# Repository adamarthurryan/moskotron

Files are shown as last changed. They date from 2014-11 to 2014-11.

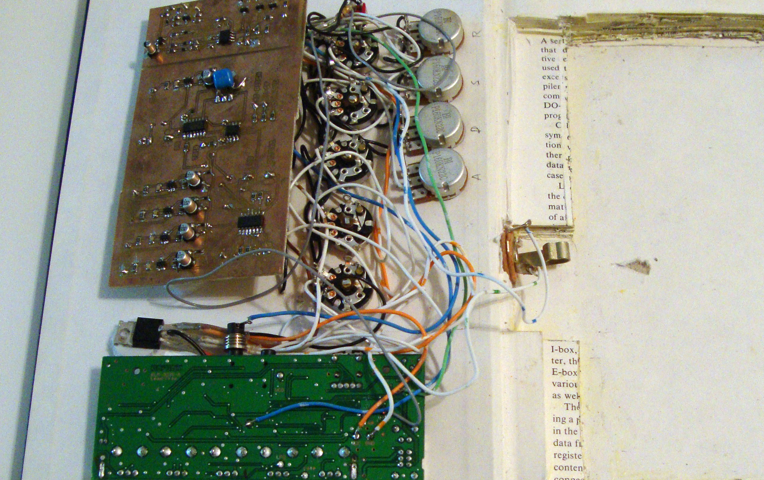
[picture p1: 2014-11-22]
documentation/book open - detail.jpg

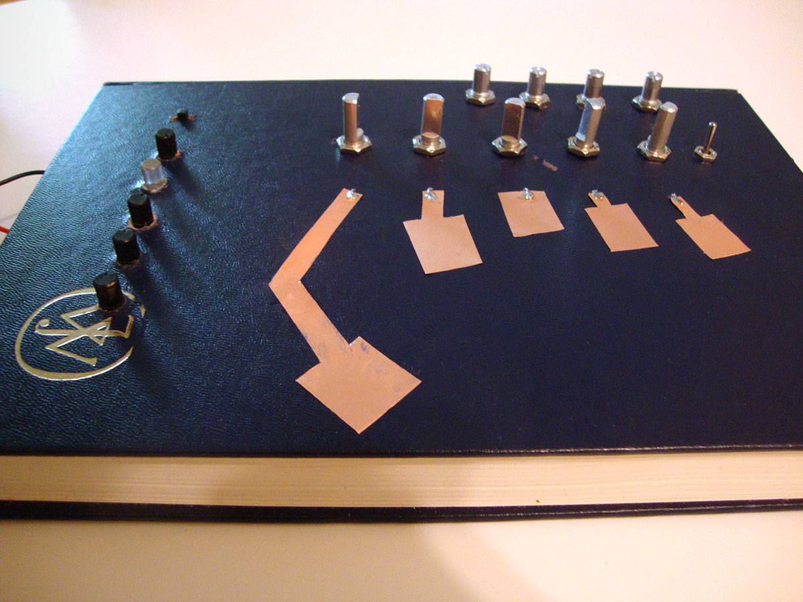
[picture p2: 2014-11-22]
documentation/book closed - small.jpg

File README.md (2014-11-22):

moskotron
=========

A unique analog audio synthesizer. Built with and for Alex Moskos - aka Drainolith. 

Audio is generated by a Korg Monotron, which is extended by wiring in two new boards: 
an ADSR enveloped waveshaper and a 5-key tunable touch keyboard.
The keyboard can be tuned to any scale - conventional, microtonal or weird.

The entire synthesizer was encased in a book - for effect.

See http://madanworb.com/blog/2012/08/15/moskotron/ for video of Alex trying it out for the first time.

Schematics and burnable pcb layouts are available in the documentation folder.

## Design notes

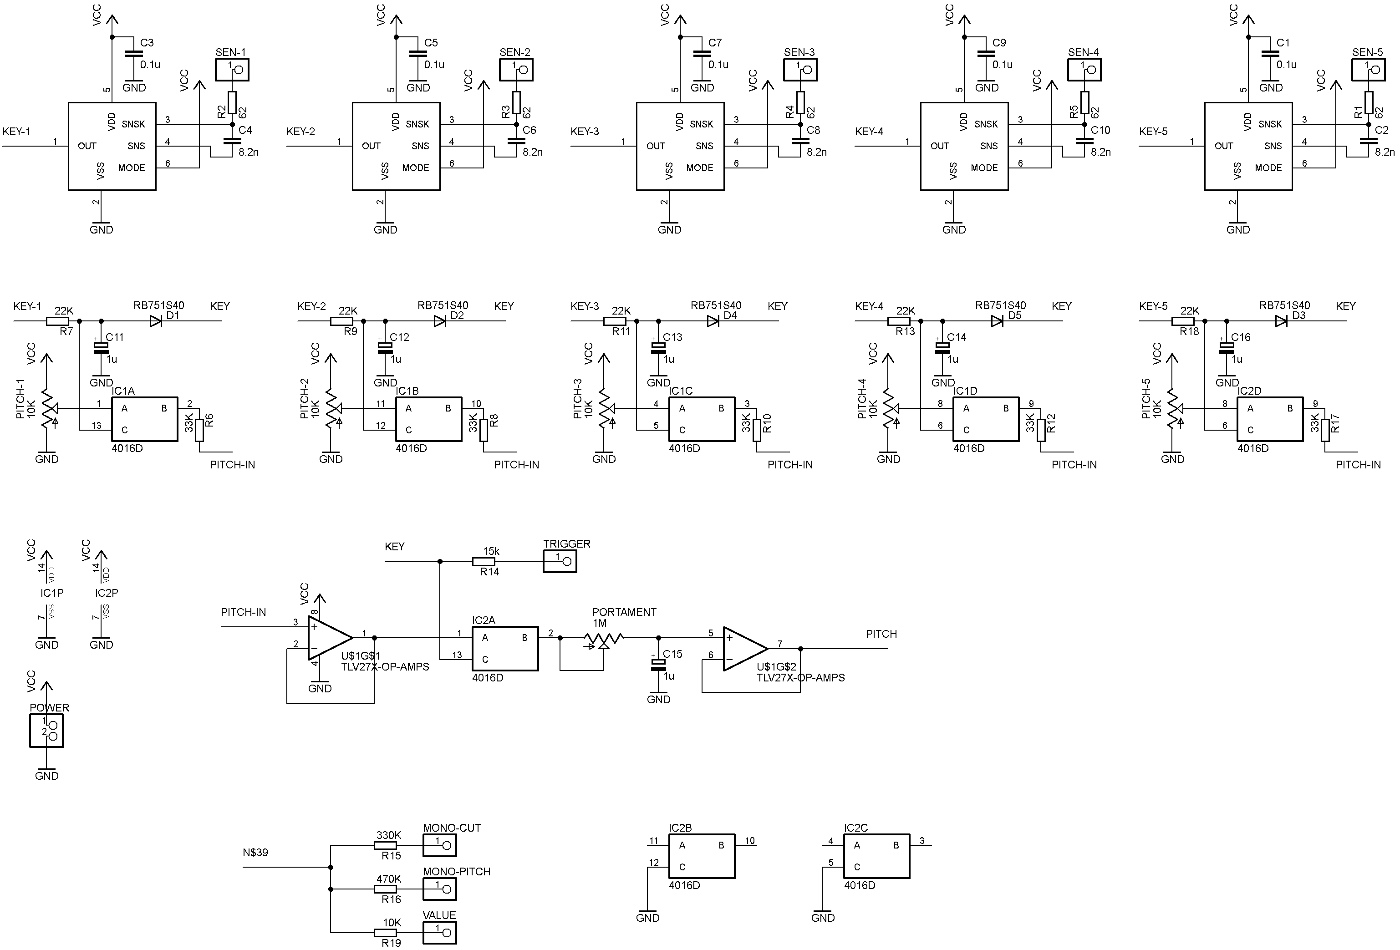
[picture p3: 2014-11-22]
documentation/pitch input schematic.png

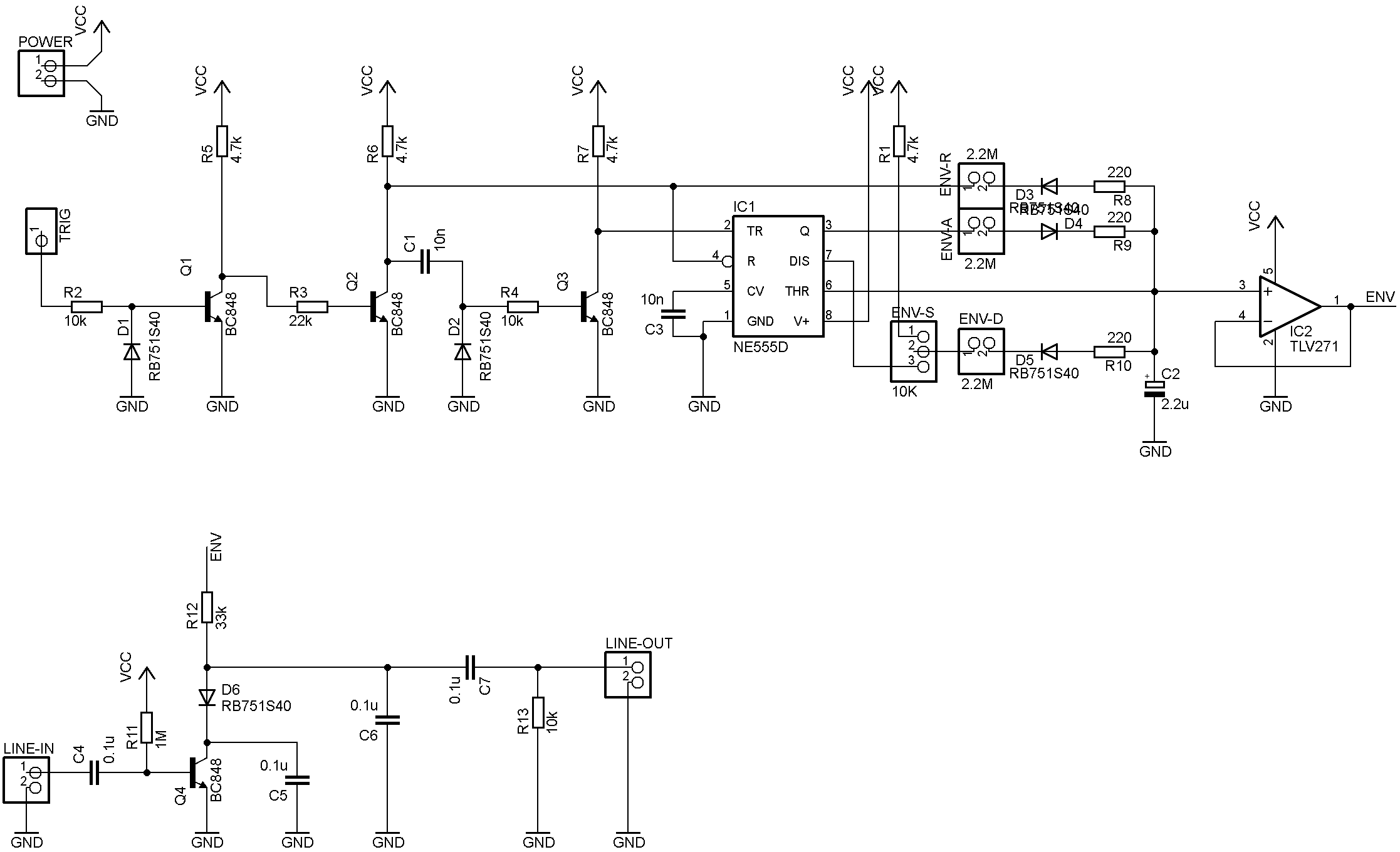
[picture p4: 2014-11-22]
documentation/adsr vca schematic.png

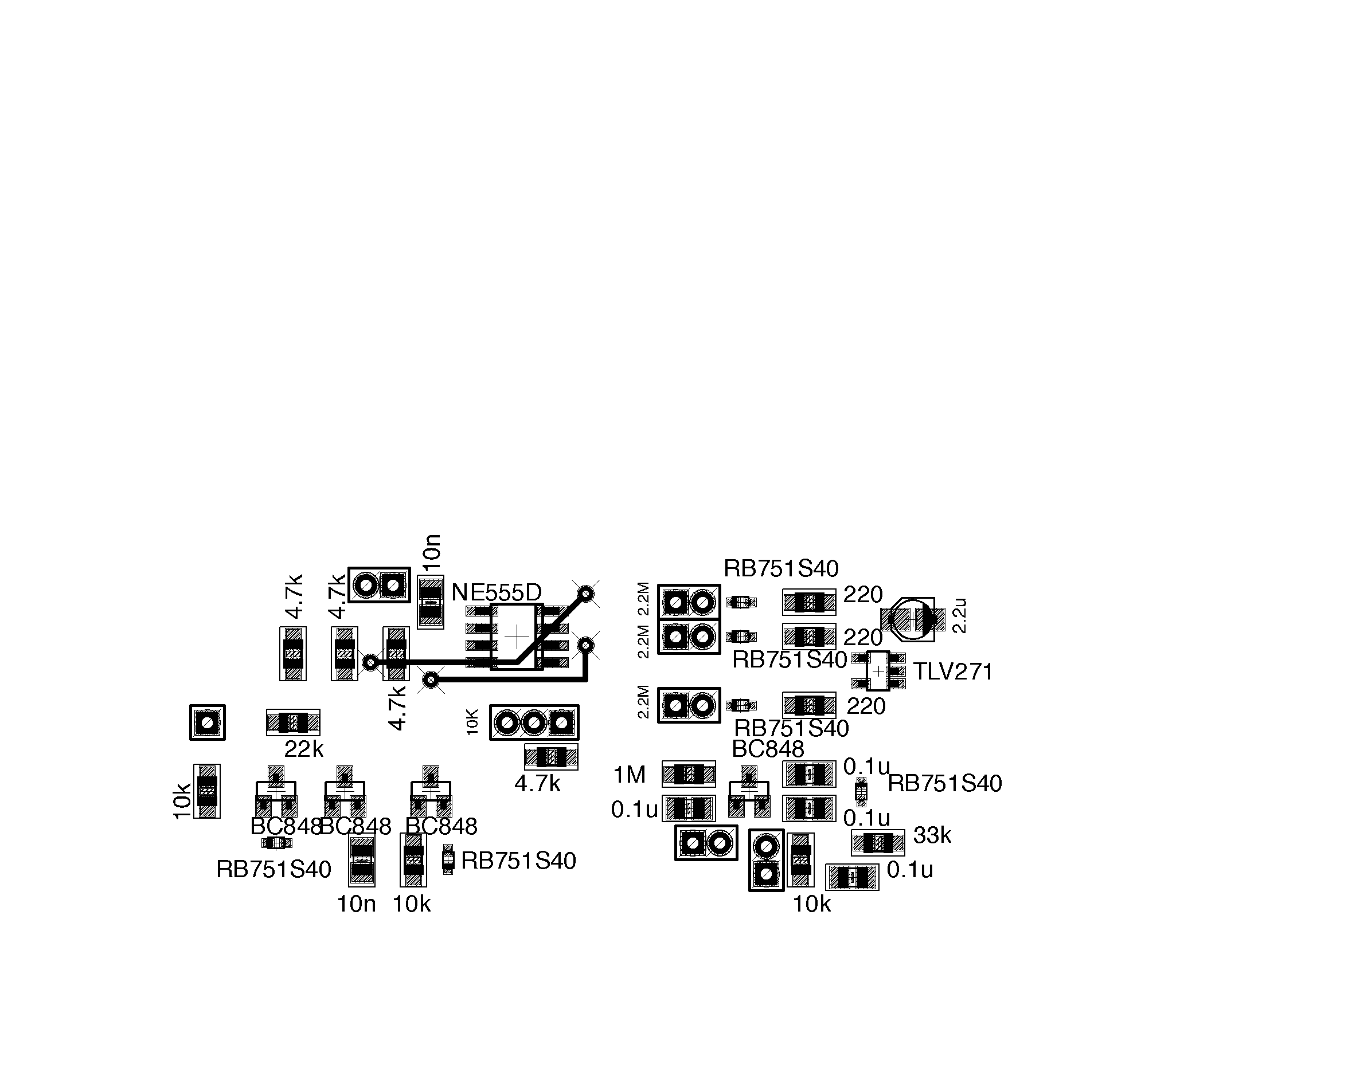
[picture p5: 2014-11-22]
adsr and vca/placement.png

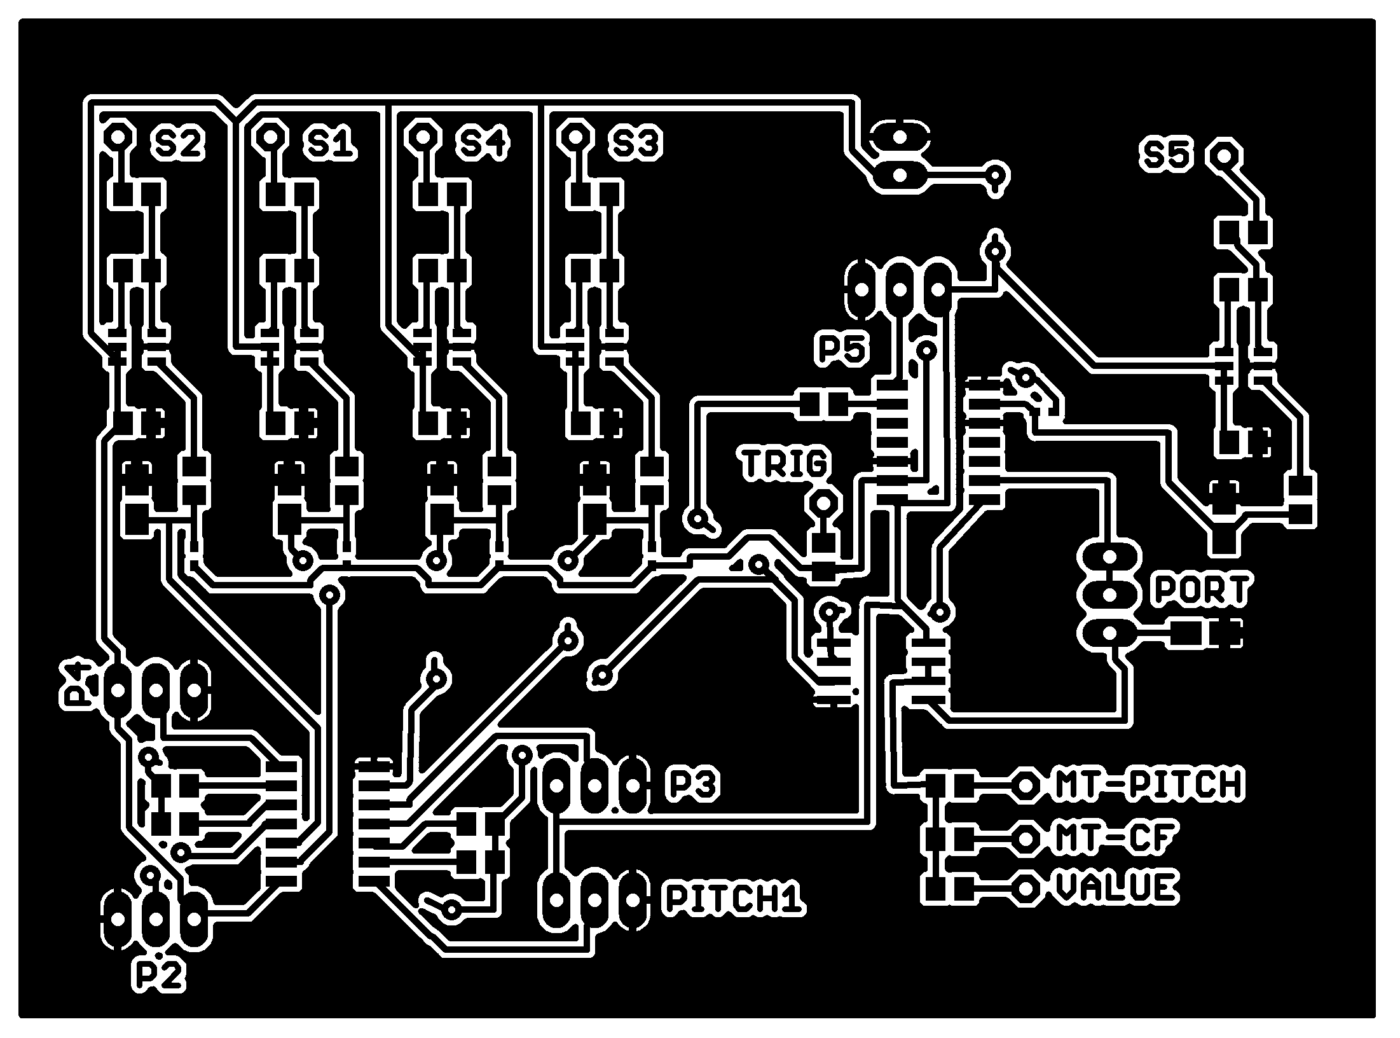
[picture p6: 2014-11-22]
pitch input/top.png

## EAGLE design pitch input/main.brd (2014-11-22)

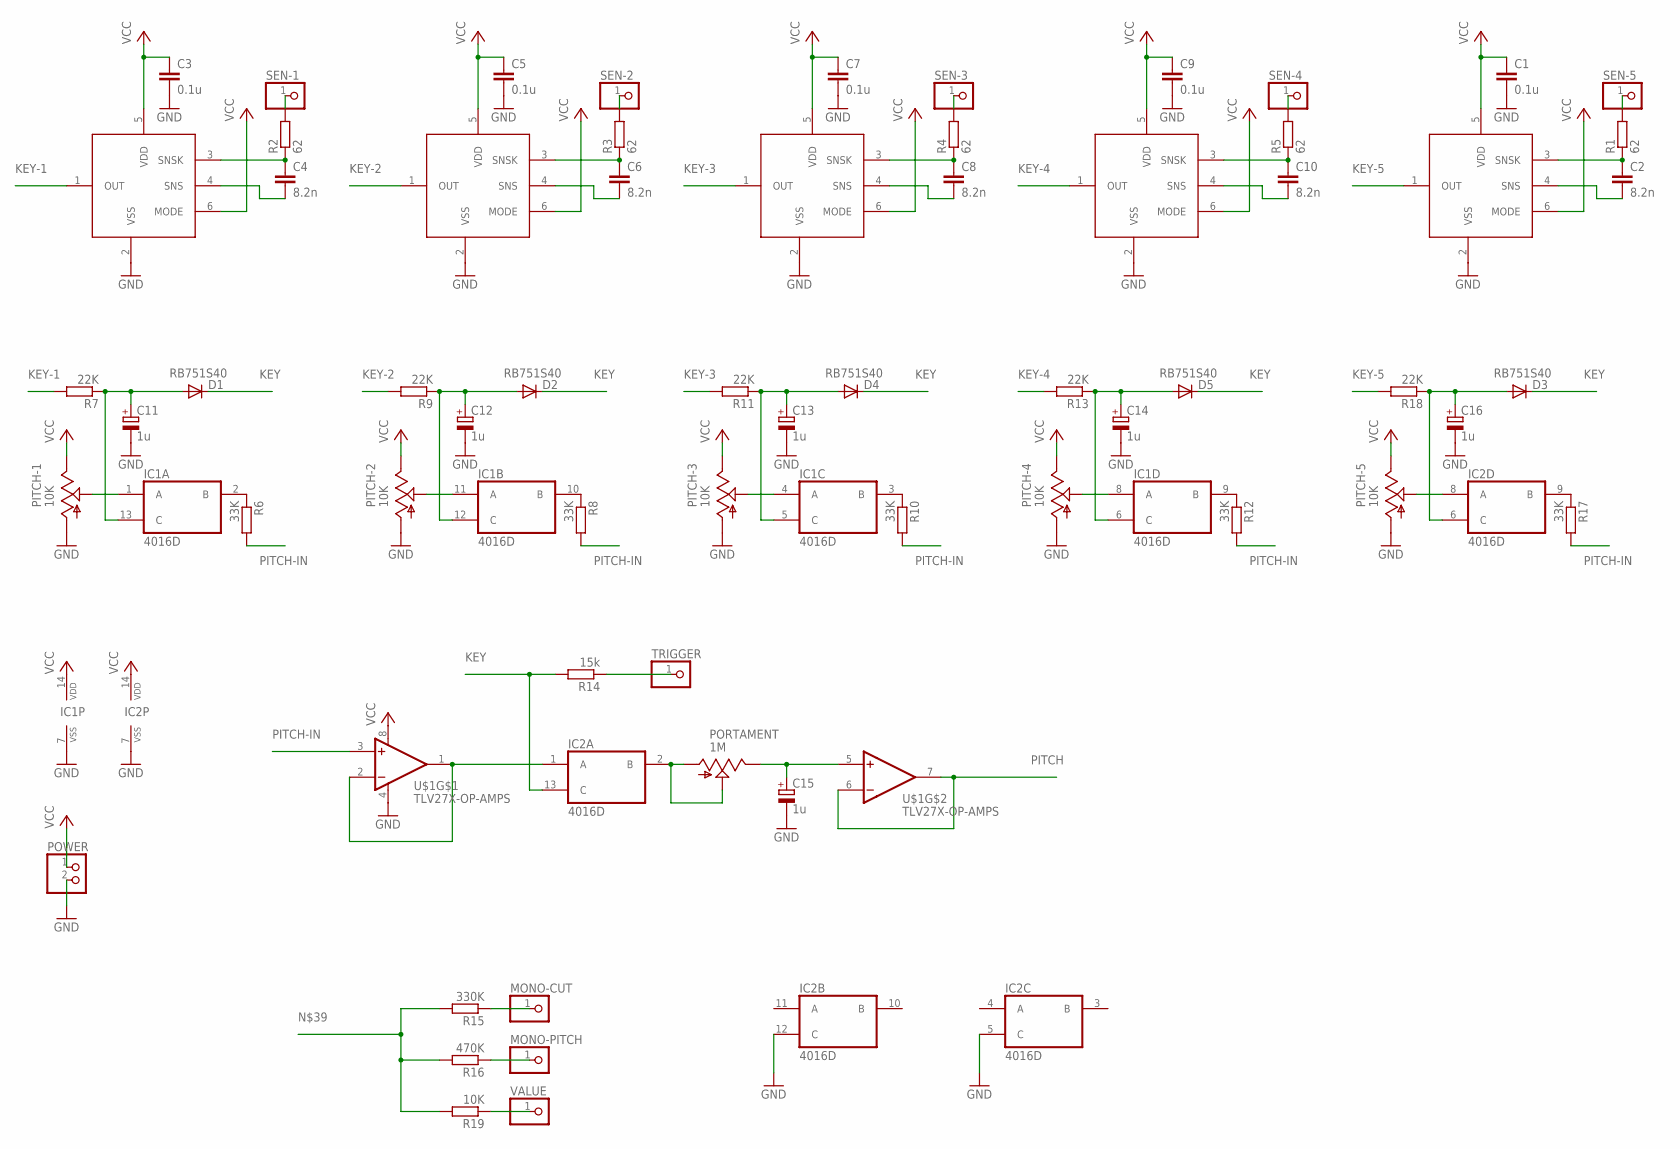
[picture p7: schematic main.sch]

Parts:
C1, C3, C5, C7, C9: 0.1u; C0805
C2, C4, C6, C8, C10: 8.2n; C0805
C11, C12, C13, C14, C15, C16: 1u; PANASONIC_A
D1, D2, D3, D4, D5: RB751S40; SOD523
IC1, IC2: 4016D; SO14
MONO-CUT: PINHD-1X1; 1X01
MONO-PITCH: PINHD-1X1; 1X01
PITCH-1, PITCH-2, PITCH-3, PITCH-4, PITCH-5: 10K; PIN-1X03
PORTAMENT: 1M; PIN-1X03
POWER: PINHD-1X2; 1X02
R1, R2, R3, R4, R5: 62; R0805
R6, R8, R10, R12, R17: 33K; R0805
R7, R9, R11, R13, R18: 22K; R0805
R14: 15k; R0805
R15: 330K; R0805
R16: 470K; R0805
R19: 10K; R0805
SEN-1, SEN-2, SEN-3, SEN-4, SEN-5: PINHD-1X1; 1X01
TRIGGER: PINHD-1X1; 1X01
U$1: TLV27X-OP-AMPS; SOIC8
U$2, U$3, U$4, U$5, U$6: AT42QT1010; SOT23-6L
VALUE: PINHD-1X1; 1X01

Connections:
GND: C1.2, C3.2, C5.2, C7.2, C9.2, C11.-, C12.-, C13.-, C14.-, C15.-, C16.-, IC1.7 (VSS), IC2.5 (C), IC2.7 (VSS), IC2.12 (C), PITCH-1.1 (A), PITCH-2.1 (A), PITCH-3.1 (A), PITCH-4.1 (A), PITCH-5.1 (A), POWER.2, U$1.4 (V-), U$2.2 (VSS), U$3.2 (VSS), U$4.2 (VSS), U$5.2 (VSS), U$6.2 (VSS)
KEY: D1.C, D2.C, D3.C, D4.C, D5.C, IC2.13 (C), R14.2
KEY-1: R7.2, U$2.1 (OUT)
KEY-2: R9.2, U$3.1 (OUT)
KEY-3: R11.2, U$4.1 (OUT)
KEY-4: R13.2, U$5.1 (OUT)
KEY-5: R18.2, U$6.1 (OUT)
unnamed: C4.2, U$2.4 (SNS)
unnamed: C4.1, R2.1, U$2.3 (SNSK)
unnamed: R2.2, SEN-1.1
unnamed: C6.2, U$3.4 (SNS)
unnamed: C6.1, R3.1, U$3.3 (SNSK)
unnamed: R3.2, SEN-2.1
unnamed: C8.2, U$4.4 (SNS)
unnamed: C8.1, R4.1, U$4.3 (SNSK)
unnamed: R4.2, SEN-3.1
unnamed: C10.2, U$5.4 (SNS)
unnamed: C10.1, R5.1, U$5.3 (SNSK)
unnamed: R5.2, SEN-4.1
unnamed: IC1.1 (A), PITCH-1.2 (S)
unnamed: IC1.2 (B), R6.1
unnamed: C11.+, D1.A, IC1.13 (C), R7.1
unnamed: IC1.11 (A), PITCH-2.2 (S)
unnamed: IC1.10 (B), R8.1
unnamed: C12.+, D2.A, IC1.12 (C), R9.1
unnamed: IC1.4 (A), PITCH-3.2 (S)
unnamed: IC1.3 (B), R10.1
unnamed: C13.+, D4.A, IC1.5 (C), R11.1
unnamed: IC1.8 (A), PITCH-4.2 (S)
unnamed: IC1.9 (B), R12.1
unnamed: C14.+, D5.A, IC1.6 (C), R13.1
unnamed: IC2.1 (A), U$1.1 (OUT), U$1.2 (-IN)
unnamed: IC2.2 (B), PORTAMENT.1 (A), PORTAMENT.2 (S)
unnamed: MONO-PITCH.1, R16.1
unnamed: C15.+, PORTAMENT.3 (E), U$1.5 (+IN)
unnamed: MONO-CUT.1, R15.1
unnamed: C2.2, U$6.4 (SNS)
unnamed: C2.1, R1.1, U$6.3 (SNSK)
unnamed: R1.2, SEN-5.1
unnamed: IC2.8 (A), PITCH-5.2 (S)
unnamed: C16.+, D3.A, IC2.6 (C), R18.1
unnamed: IC2.9 (B), R17.1
unnamed: R15.2, R16.2, R19.2
unnamed: R19.1, VALUE.1
PITCH: U$1.6 (-IN), U$1.7 (OUT)
PITCH-IN: R6.2, R8.2, R10.2, R12.2, R17.2, U$1.3 (+IN)
TRIG: R14.1, TRIGGER.1
VCC: C1.1, C3.1, C5.1, C7.1, C9.1, IC1.14 (VDD), IC2.14 (VDD), PITCH-1.3 (E), PITCH-2.3 (E), PITCH-3.3 (E), PITCH-4.3 (E), PITCH-5.3 (E), POWER.1, U$1.8 (V+), U$2.5 (VDD), U$2.6 (MODE), U$3.5 (VDD), U$3.6 (MODE), U$4.5 (VDD), U$4.6 (MODE), U$5.5 (VDD), U$5.6 (MODE), U$6.5 (VDD), U$6.6 (MODE)

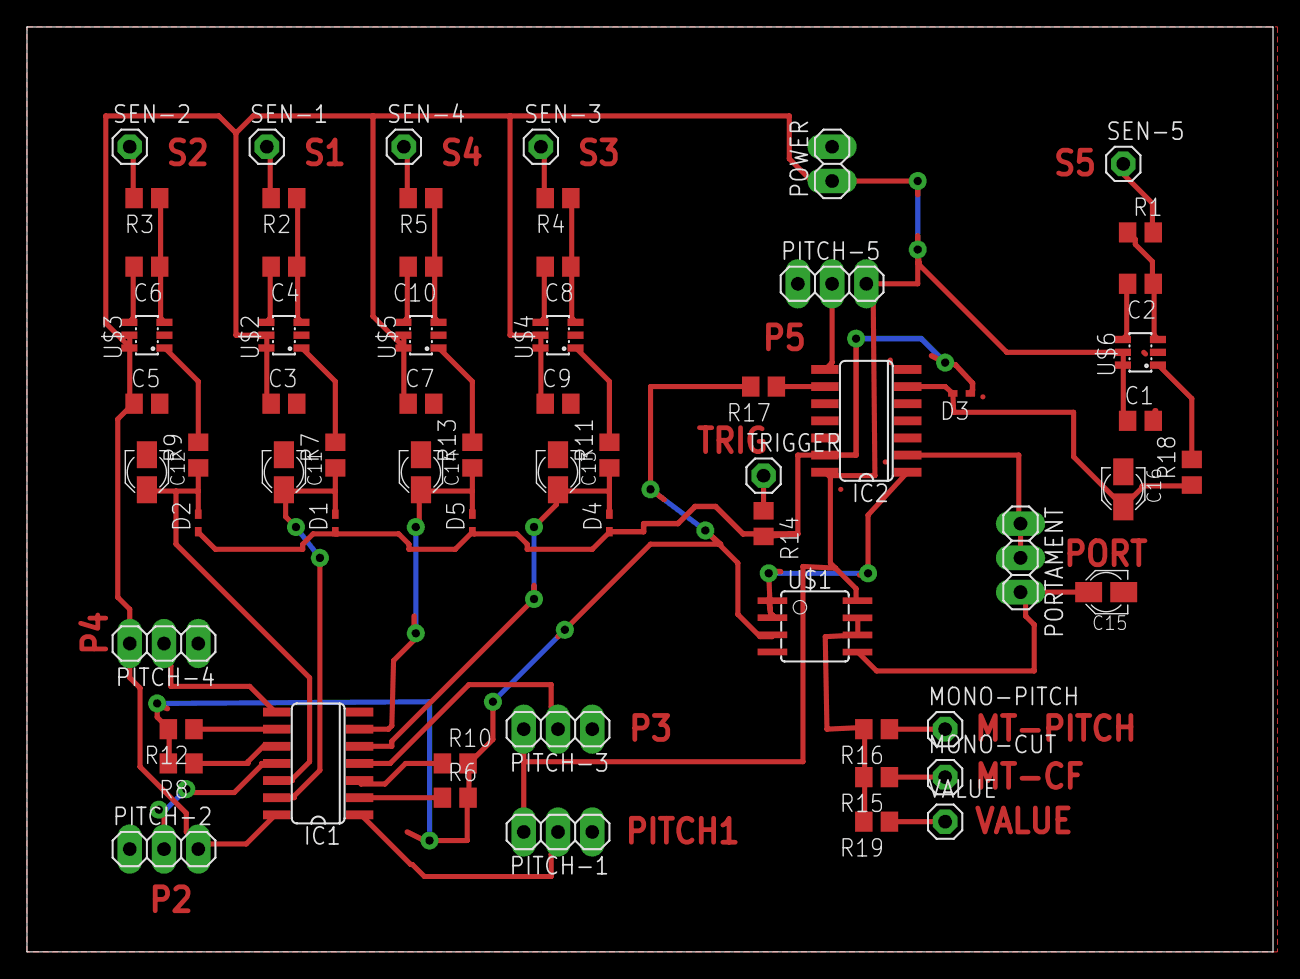
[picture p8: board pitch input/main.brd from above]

Board: 2 copper layers, 92.4 x 68.6 mm, 64 parts (0 on the bottom side), 48 nets.

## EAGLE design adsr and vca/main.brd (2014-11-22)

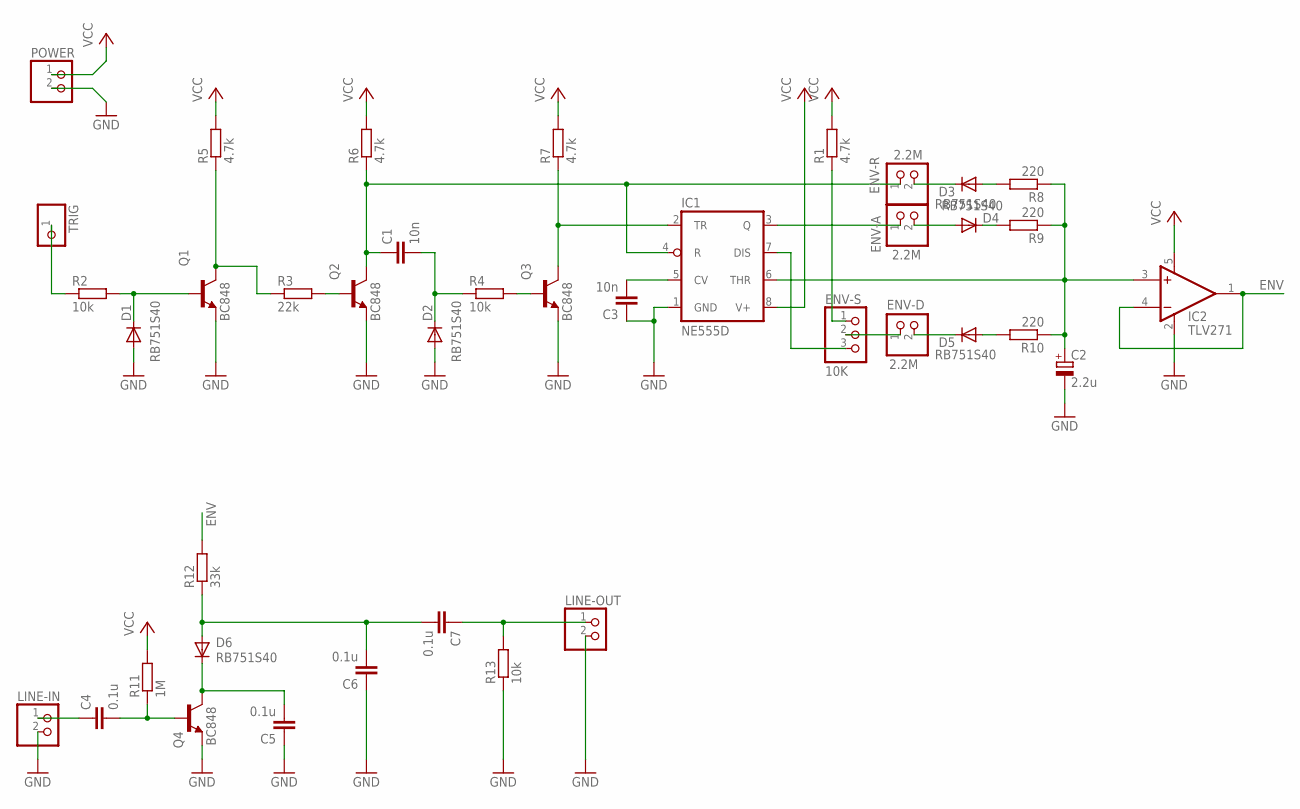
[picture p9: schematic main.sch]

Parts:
C1, C3: 10n; C0805
C2: 2.2u; PANASONIC_A
C4, C5, C6, C7: 0.1u; C0805
D1, D2, D3, D4, D5, D6: RB751S40; SOD523
ENV-A: 2.2M; 1X02M
ENV-D: 2.2M; 1X02M
ENV-R: 2.2M; 1X02M
ENV-S: 10K; 1X03M
IC1: NE555D; SO08
IC2: TLV271; SOT23-5
LINE-IN: PINHD-1X02_2.00; 1X02M
LINE-OUT: PINHD-1X02_2.00; 1X02M
POWER: PINHD-1X02_2.00; 1X02M
Q1, Q2, Q3, Q4: BC848; SOT23
R1, R5, R6, R7: 4.7k; R0805W
R2, R4, R13: 10k; R0805W
R3: 22k; R0805W
R8, R9, R10: 220; R0805W
R11: 1M; R0805W
R12: 33k; R0805W
TRIG: PINHD-1X01_2.00; 1X01M

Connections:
ENV: IC2.1 (OUT), IC2.4 (-IN), R12.2
GND: C2.-, C3.1, C5.1, C6.1, D1.A, D2.A, IC1.1 (GND), IC2.2 (V-), LINE-IN.2, LINE-OUT.2, POWER.2, Q1.2 (E), Q2.2 (E), Q3.2 (E), Q4.2 (E), R13.1
unnamed: R2.1, TRIG.1
unnamed: D1.C, Q1.1 (B), R2.2
unnamed: Q1.3 (C), R3.1, R5.1
unnamed: Q2.1 (B), R3.2
unnamed: C1.1, ENV-R.1, IC1.4 (R), Q2.3 (C), R6.1
unnamed: C1.2, D2.C, R4.1
unnamed: Q3.1 (B), R4.2
unnamed: C7.1, LINE-OUT.1, R13.2
unnamed: D5.C, ENV-D.2
unnamed: ENV-D.1, ENV-S.2
unnamed: ENV-S.3, IC1.7 (DIS)
unnamed: IC1.2 (TR), Q3.3 (C), R7.1
unnamed: C3.2, IC1.5 (CV)
unnamed: D3.A, R8.2
unnamed: D3.C, ENV-R.2
unnamed: C2.+, IC1.6 (THR), IC2.3 (+IN), R8.1, R9.1, R10.1
unnamed: ENV-A.1, IC1.3 (Q)
unnamed: D4.A, ENV-A.2
unnamed: D4.C, R9.2
unnamed: D5.A, R10.2
unnamed: ENV-S.1, R1.1
unnamed: C4.1, LINE-IN.1
unnamed: C4.2, Q4.1 (B), R11.1
unnamed: C5.2, D6.C, Q4.3 (C)
unnamed: C6.2, C7.2, D6.A, R12.1
VCC: IC1.8 (V+), IC2.5 (V+), POWER.1, R1.2, R5.2, R6.2, R7.2, R11.2

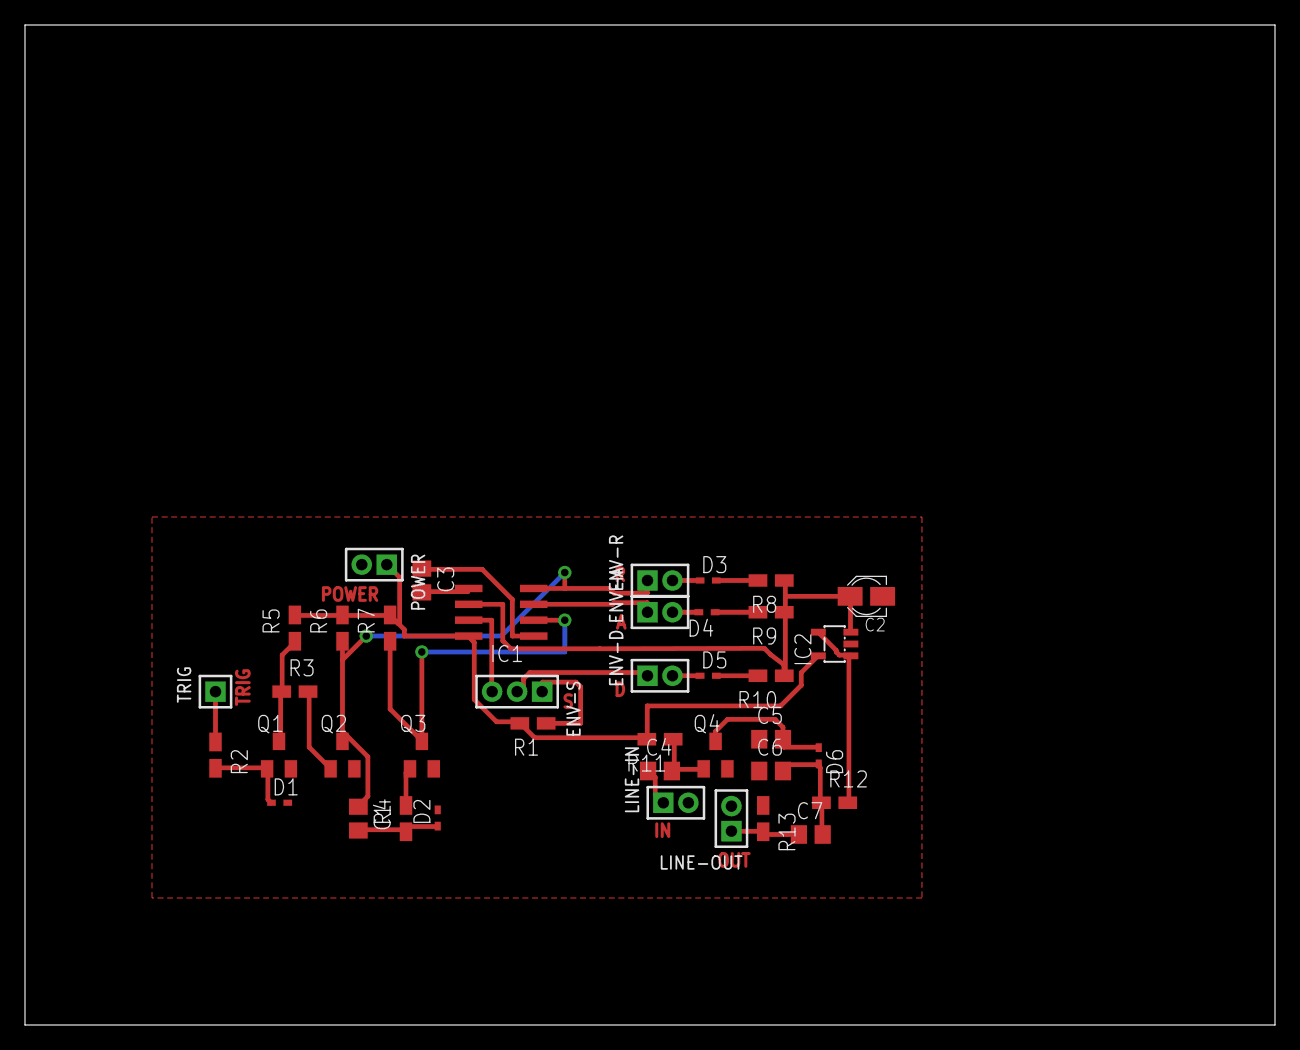
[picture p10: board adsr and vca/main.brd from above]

Board: 2 copper layers, 100.0 x 80.0 mm, 40 parts (0 on the bottom side), 28 nets.
